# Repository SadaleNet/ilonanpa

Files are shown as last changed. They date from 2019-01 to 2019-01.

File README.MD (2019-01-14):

# Ilo Nanpa - Toki Pona Numeral Calculator

(sina sona e toki pona, la o tawa lipu [https://ilonanpa.sadale.net/](https://ilonanpa.sadale.net/). mi kepeken toki ike tan ni: nimi sona "Programming" li ike. toki ike Inli taso li lon lipu ni.)

Ilo Nanpa is a hardware calculator designed for Toki Pona Numeral. [Toki Pona](http://tokipona.org/) is a minimalist constructed language designed by jan Sonja with an obscure, non-base-10 numeral system.

This repository contains the source code of the firmware as well as the source files of hardware design. This readme file mainly describes the procedure of building the firmware as well as working with factory mode. For the usage of this device and other technical details, please refer to [the official English blogpost of Ilo Nanpa on sadale.net](https://sadale.net/58/).

# Repository Structure

* src/ - source code of the firmware
* pcb/ - KiCad hardware design files
* bin/ - Compiled source code (generated after running Makefile)

# Microcontroller

The microcontroller of this project is STM8S001J3.

# Dependencies

* Make (for Makefile)
* Compiler: sdcc
* Firmware uploading tool: stm8flash, to be used with stlinkv2.
* PCB Software: KiCad (for modification of hardware design. It isn't needed for firmware development)

# Building and Flashing the Firmware

* Run `make` to build the firmware.

* Connect stlink with Ilo Nanpa. On the backside of the device, there's a 3-pin male header on the top-left corner. The pin 1 is Vcc, pin 2 is ground and pin 3 is SWIM.

* Run `make flash-opt-bytes` to flash the option bytes (fusebit-like configuration). It maps ADC channel 2 to the ala-wan-tu button group. This operation only need to be performed once for each microcontroller. For some reason, the first run returns me an error. I have to run this command twice to get it work.

* Run `make flash` to upload the firmware to the microcontroller. For some reason, the first run of the command often fails. Perhaps it has something to do with clock configuration. I have to run this command twice to get it uploaded.

# Reprogramming the Device

To reprogram the device, hold the "pana" button before powering up the device. This prevents the device from leaving programming mode. As soon as "pana" is released, the device would leave programming mode and enter normal operation mode.

# Factory Mode

Due to the design of the device, ADC calibration procedure has to be performed for getting the button detection of the device work. This can be performed using factory mode. In addition, factory mode is able to perform key tests and LED brightness adjustment.

** If you're a holder of Ilo Nanpa and you have no idea on what this mode does, please do NOT enter factory mode. This mode would cause your device not to be able to properly detect key presses if it isn't used properly. **

Please ensure that you aren't touching any LEDs or resistors with your fingers during the process.

To enter factory mode:

1. Hold down the "ala" button and power the device on.

2. Wait for 5 seconds. The LEDs suno9,10,11,12 would turn on.

3. Press the buttons in the following sequence. ala, pana, luka, pana, ala, luka, luka, pana. If you press any of them wrong, the firmware would enter normal mode and would not enter factory mode.

4. Slide the en/weka slider switch to `en` position.

5. The LEDs suno1 and suno12 should light up. If suno8 is also lit, you're too slow and you have to slide the en/weka slider to `weka` position and back to `en` position again.

6. You're now in ADC calibration scene. Press the buttons in this sequence for 5 times: ala, wan, tu, luka, mute, ali, pana, kama, tenpo. This calibrates the ADC values when the slider is in `en` position. After this step, the ADC calibration values are saved to the EEPROM.

7. The LEDs suno1,8,12 should be lit. You've entered key test scene. The buttons are grouped as shown below:

	* suno1,2,3,4 <=> RELEASED,ala,wan,tu
	* suno8,9,10,11 <=> RELEASED,luka,mute,ali
	* suno12,13,14,15 <=> RELEASED,pana,kama,tenpo

	For example, when ala is pressed, suno2 would be lit. When wan is pressed, suno3 would be lit. When tu is pressed, suno4 would be lit. When none of ala, wan and tu is pressed, suno1 would be lit.

8. Repeat step 4 to 7, but with slider switch positioned at `weka` instead of `en`.

9. If you're in key test scene, you can enter brightness adjustment scene. To enter brightness adjustment scene, hold ala, luka and tenpo at the same time.

10. The higher the maxActionCount, the lower the brightness. In brightness adjustment scene, press wan to reduce maxActionCount by 10, tu to reduce maxActionCount by 1, mute to increase maxActionCount by 1, ali to increase maxActionCount by 10. The number shown on the LEDs is the current maxActionCount in Toki Pona Numeral.

11. To get back to key test scene from brightness adjustment scene, hold ala, luka and tenpo at the same time. To get back to ADC calibration scene, slide the slider switch in any scene.

# Working with Hardware Design
Just open up `pcb/ilonanpa.pro` with KiCad. The documentation of KiCad can be found on their website.

Please notice that unusual electronic designator is being used. Instead of R1, R2, R3 for resistors, we have awen1, awen2, awen3. It's designed in this way because this device is designed to have Toki Pona culture in mind. In case you're confused, please refer to the electronic symbol.

# License
This project is licensed under BSD 2-clause license.

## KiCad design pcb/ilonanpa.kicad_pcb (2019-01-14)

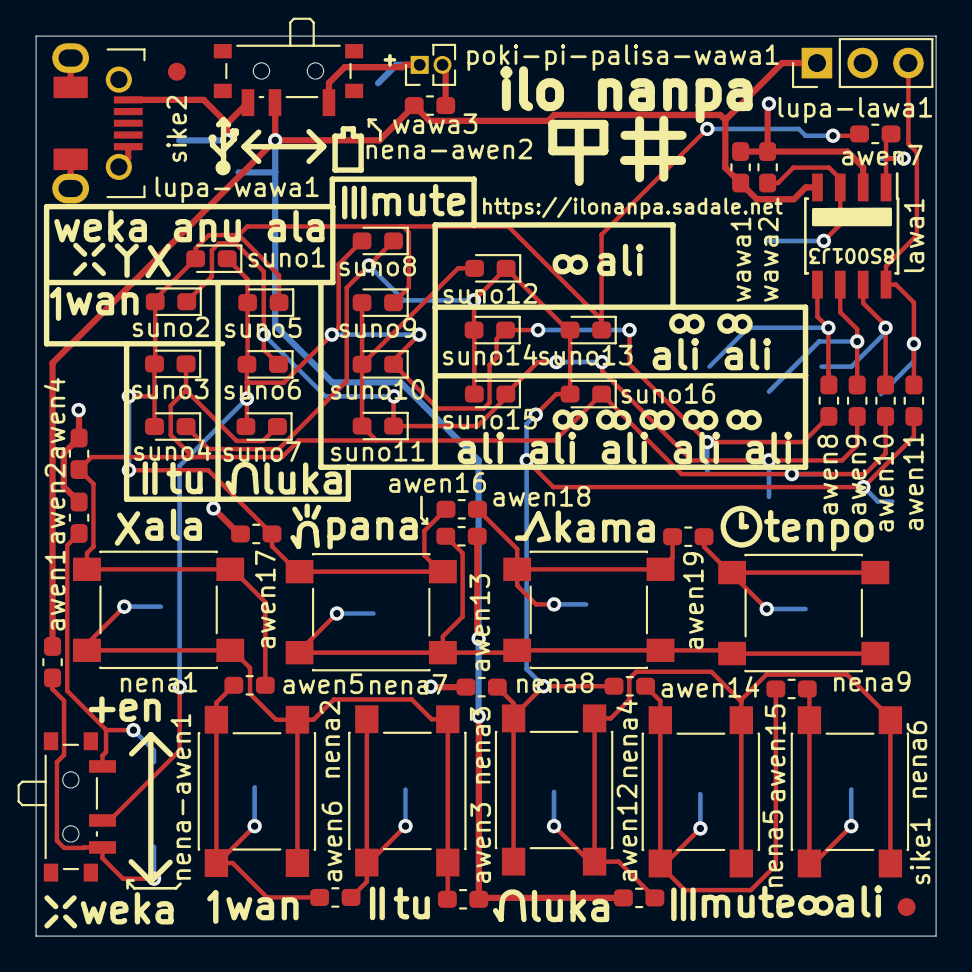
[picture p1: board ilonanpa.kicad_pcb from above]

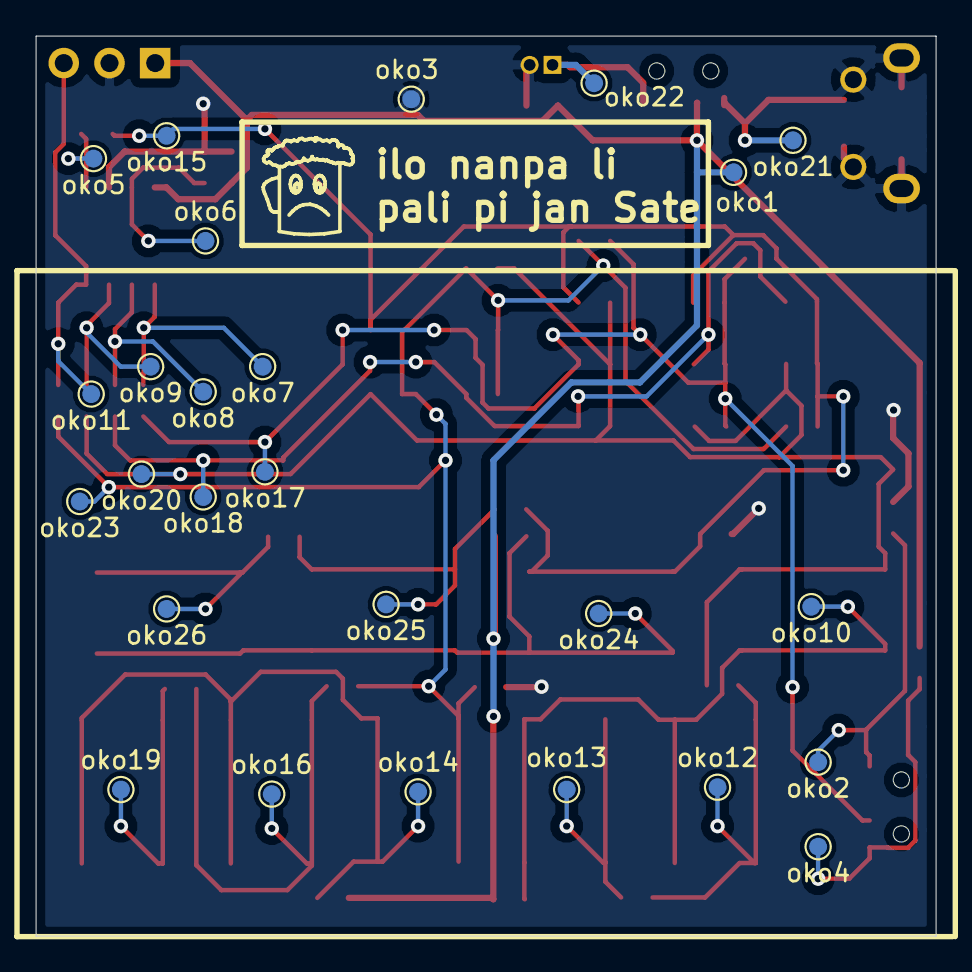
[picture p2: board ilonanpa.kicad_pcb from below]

Board: 2 copper layers, 50.0 x 50.0 mm, 81 parts (26 on the bottom side), 26 nets.

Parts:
awen1, awen2, awen4, awen13, awen17: 470k; R_0603_1608Metric_Pad1.05x0.95mm_HandSolder
awen3, awen12, awen16: 10k; R_0603_1608Metric_Pad1.05x0.95mm_HandSolder
awen5, awen6, awen14, awen15, awen18, awen19: 20k; R_0603_1608Metric_Pad1.05x0.95mm_HandSolder
awen7, awen8, awen9, awen10, awen11: 120; R_0603_1608Metric_Pad1.05x0.95mm_HandSolder
lawa1: STM8S001J3; SOIC-8_3.9x4.9mm_P1.27mm
lupa-lawa1: lupa lawa; PinHeader_1x03_P2.54mm_Vertical
lupa-wawa1: USB_B_Micro; USB_Micro-B_A01SB141B1-067
nena1: ala; SW_SPST_PTS645
nena2: wan; SW_SPST_PTS645
nena3: tu; SW_SPST_PTS645
nena4: luka; SW_SPST_PTS645
nena5: mute; SW_SPST_PTS645
nena6: ali; SW_SPST_PTS645
nena7: pana; SW_SPST_PTS645
nena8: kama; SW_SPST_PTS645
nena9: tenpo; SW_SPST_PTS645
nena-awen1: en anu weka; SW_SPDT_PCM12
nena-awen2: ante wawa; SW_SPDT_PCM12
oko1, oko2, oko3, oko4, oko5, oko6, oko7, oko8, oko9, oko10, oko11, oko12, oko13, oko14, oko15, oko16, oko17, oko18, oko19, oko20, oko21, oko22, oko23, oko24, oko25, oko26: oko; TestPoint_Pad_D1.0mm
poki-pi-palisa-wawa1: wawa palisa "AAA" tu wan; PinHeader_1x02_P1.27mm_Vertical
sike1, sike2: Fiducial_1mm_Dia_2mm_Outer
suno1: weka anu ala; LED_0603_1608Metric_Pad1.05x0.95mm_HandSolder
suno2: wan; LED_0603_1608Metric_Pad1.05x0.95mm_HandSolder
suno3, suno4: tu; LED_0603_1608Metric_Pad1.05x0.95mm_HandSolder
suno5, suno6, suno7: luka; LED_0603_1608Metric_Pad1.05x0.95mm_HandSolder
suno8, suno9, suno10, suno11: mute; LED_0603_1608Metric_Pad1.05x0.95mm_HandSolder
suno12: ali; LED_0603_1608Metric_Pad1.05x0.95mm_HandSolder
suno13, suno14: ali ali; LED_0603_1608Metric_Pad1.05x0.95mm_HandSolder
suno15, suno16: ali ali ali ali ali; LED_0603_1608Metric_Pad1.05x0.95mm_HandSolder
wawa1: 100n; C_0603_1608Metric_Pad1.05x0.95mm_HandSolder
wawa2: 2u2; C_0603_1608Metric_Pad1.05x0.95mm_HandSolder
wawa3: 10u; C_0603_1608Metric_Pad1.05x0.95mm_HandSolder

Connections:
/1: awen7.2, lawa1.1, oko5.1
/5: awen8.2, lawa1.5, oko7.1
/6: awen9.2, lawa1.6, oko8.1
/7: awen10.2, lawa1.7, oko9.1
/8: awen11.2, lawa1.8, lupa-lawa1.3, oko11.1
/A: awen7.1, awen17.2, awen18.1, nena7.2, oko15.1, suno1.2, suno2.2, suno3.2, suno4.2, suno5.1, suno9.1, suno13.1
/AIN2: awen4.2, awen5.1, awen10.1, nena1.2, oko20.1, suno3.1, suno7.1, suno9.2, suno10.2, suno11.2, suno12.2, suno16.1
/AIN4,5: awen11.1, awen13.2, awen14.1, nena4.2, oko23.1, suno4.1, suno8.1, suno12.1, suno13.2, suno14.2, suno15.2, suno16.2
/B: awen8.1, nena-awen1.2, oko17.1, suno1.1, suno5.2, suno6.2, suno7.2, suno8.2, suno10.1, suno14.1
/C: awen9.1, oko18.1, suno2.1, suno6.1, suno11.1, suno15.1
GND: awen2.2, awen4.1, awen13.1, awen17.1, lawa1.2, lupa-lawa1.2, lupa-wawa1.5, lupa-wawa1.6, oko3.1, poki-pi-palisa-wawa1.2, wawa1.1, wawa2.1, wawa3.2
unnamed: awen1.2, nena-awen1.3, oko4.1
unnamed: awen2.1, nena-awen1.1, oko2.1
unnamed: awen3.2, nena1.1, nena2.1, nena3.1, oko10.1
unnamed: awen5.2, awen6.1, nena2.2, oko12.1
unnamed: awen6.2, nena3.2, oko13.1
unnamed: awen12.2, nena4.1, nena5.1, nena6.1, oko14.1
unnamed: awen14.2, awen15.1, nena5.2, oko16.1
unnamed: awen15.2, nena6.2, oko19.1
unnamed: awen16.2, nena7.1, nena8.1, nena9.1, oko24.1
unnamed: awen18.2, awen19.1, nena8.2, oko25.1
unnamed: awen19.2, nena9.2, oko26.1
unnamed: lawa1.3, oko6.1, wawa2.2
unnamed: lupa-wawa1.1, nena-awen2.3, oko21.1
unnamed: nena-awen2.1, oko22.1, poki-pi-palisa-wawa1.1
VDD: awen1.1, awen3.1, awen12.1, awen16.1, lawa1.4, lupa-lawa1.1, nena-awen2.2, oko1.1, wawa1.2, wawa3.1

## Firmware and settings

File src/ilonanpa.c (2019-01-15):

/*
Copyright 2019 Wong Cho Ching <https://sadale.net>

Redistribution and use in source and binary forms, with or without modification, are permitted provided that the following conditions are met:

1. Redistributions of source code must retain the above copyright notice, this list of conditions and the following disclaimer.

2. Redistributions in binary form must reproduce the above copyright notice, this list of conditions and the following disclaimer in the documentation and/or other materials provided with the distribution.

THIS SOFTWARE IS PROVIDED BY THE COPYRIGHT HOLDERS AND CONTRIBUTORS "AS IS" AND ANY EXPRESS OR IMPLIED WARRANTIES, INCLUDING, BUT NOT LIMITED TO, THE IMPLIED WARRANTIES OF MERCHANTABILITY AND FITNESS FOR A PARTICULAR PURPOSE ARE DISCLAIMED. IN NO EVENT SHALL THE COPYRIGHT HOLDER OR CONTRIBUTORS BE LIABLE FOR ANY DIRECT, INDIRECT, INCIDENTAL, SPECIAL, EXEMPLARY, OR CONSEQUENTIAL DAMAGES (INCLUDING, BUT NOT LIMITED TO, PROCUREMENT OF SUBSTITUTE GOODS OR SERVICES; LOSS OF USE, DATA, OR PROFITS; OR BUSINESS INTERRUPTION) HOWEVER CAUSED AND ON ANY THEORY OF LIABILITY, WHETHER IN CONTRACT, STRICT LIABILITY, OR TORT (INCLUDING NEGLIGENCE OR OTHERWISE) ARISING IN ANY WAY OUT OF THE USE OF THIS SOFTWARE, EVEN IF ADVISED OF THE POSSIBILITY OF SUCH DAMAGE.
*/

#include <stdbool.h>
#include <stdint.h>
#include "stm8.h"

//Addresses of EEPROM values.
//For AWT/LMA/PKT, each of them are array of six values.
//For AWT, The first value is the minimum value of ALA reading at EN position
//The second value is the minimum value of WAN reading at EN position
//The third value is the minimum value of TU reading at EN position
//The next three values are the WEKA position correspondent of the previous three values.
#define EEPROM_AWT_THRESHOLD *(volatile uint16_t *)0x4000
#define EEPROM_LMA_THRESHOLD *(volatile uint16_t *)0x400C
#define EEPROM_PKT_THRESHOLD *(volatile uint16_t *)0x4018
#define EEPROM_SAVED_VALUE *(volatile int16_t *)0x4024
#define EEPROM_BRIGHTNESS *(volatile uint8_t *)0x4026
#define EEPROM_DEBUG *(volatile int16_t *)0x4028

//Timer-related handling
#define TIMER_FREQ 12500
#define MIN_MAX_ACTION_COUNTER 20
#define TIME_TO_ENTER_PASSWORD_MODE 62500 //5 seconds at 12500Hz
#define TIME_FOR_CALIBRATION_TIMEOUT 37500 //3 seconds at 12500Hz

//En/weka detection handling
#define EN_WEKA_DETECTION_FRAME 400 //en/weka should get detected every 0.032 second (at 12500Hz)
#define EN_WEKA_WAIT_FRAME 25 //We have to ensure 0.002s(25 frames) of no LEDs before checking the value of en/weka

//Minimum and maximum value that ilo nanpa can handle.
#define MAX_VALUE 1600
#define MIN_VALUE -1600

//Definition of LED ports and pins
#define LED_A_PORT    PD
#define LED_A_PIN     PIN6
#define LED_B_PORT    PA
#define LED_B_PIN     PIN3
#define LED_C_PORT    PB
#define LED_C_PIN     PIN4
#define LED_D_PORT    PC
#define LED_D_PIN     PIN4
#define LED_E_PORT    PD
#define LED_E_PIN     PIN5

//Port definition of buttons
#define EN_WEKA_PORT	PA
#define EN_WEKA_PIN		PIN3
#define AWT_PORT		PC
#define AWT_PIN			PIN4
#define LMA_PORT		PD
#define LMA_PIN			PIN5
#define PKT_PORT		PD
#define PKT_PIN			PIN6

//ADC channels for button groups
#define BUTTON_AWT_CHANNEL 2 //ala, wan, tu
#define BUTTON_LMA_CHANNEL 5 //luka, mute, ali [shared with debug pin!]
#define BUTTON_PKT_CHANNEL 6 //pana, kama, tenpo

//If the ADC reading is above this value, one of the button in the ADC group is pressed
#define MIN_ANALOG_VALUE 0x300

//For "frame" delay skipping. Used for maintaining the "fps".
uint8_t timer4TriggeredCount = 0;

//Debouncing value. A value is only accepted if the same value is read for 3 times consecutively
struct DebouncedValueU8_3 {
	uint8_t value[3];
	uint8_t offset;
};

//Push a new value to the deboucing ring buffer. Returns the debounced value on success, supplied default value on failure.
uint8_t debounced_value_u8_3_push_value(struct DebouncedValueU8_3* debouncedValueU8_3, uint8_t newValue, uint8_t defaultValue){
	debouncedValueU8_3->value[debouncedValueU8_3->offset++] = newValue;
	if(debouncedValueU8_3->offset>=sizeof(debouncedValueU8_3->value)/sizeof(*(debouncedValueU8_3->value)))
		debouncedValueU8_3->offset = 0;
	for(uint8_t i=1; i<( sizeof(debouncedValueU8_3->value)/sizeof(*(debouncedValueU8_3->value)) ); i++){
		if(debouncedValueU8_3->value[0]!=debouncedValueU8_3->value[i])
			return defaultValue; //Debounce failed. Returning the supplied default value
	}
	return debouncedValueU8_3->value[0]; //Debounce success!
}

uint16_t analog_read(uint8_t);
uint16_t analog_read_with_led_b_on(uint8_t channel);

//Detect which button is pressed based on ADC reading, current en/weka position and the threshold values supplied.
uint8_t button_read(uint16_t adcValue, bool wekaMode, volatile uint16_t *thresholds){
	uint8_t wekaOffset = wekaMode?3:0;
	if(adcValue >= thresholds[0+wekaOffset])
		return 1;
	else if(adcValue >= thresholds[1+wekaOffset])
		return 2;
	else if(adcValue >= thresholds[2+wekaOffset])
		return 3;
	else
		return 0;
}

//Function for litting charlieplex'd LEDs. 0~15: lit one LED. 
//16: lit all group A LEDs. 17: all group B. 18: C. 19: D. 20: all group A except "WEKA ANU ALA".
//16~19 is used for timer reaching minimum value (-1600)
//17~20 is used for timer reaching maximum value (1600)
//By litting 4 LEDs at once, it's brighter than litting up LED 0~15 one by one.
void litLed(int ledId) {
	#define CHARLIEPLEX_LED_OUTPUT(SRC, SINK) \
	/* Set pins to output mode */ \
	PORT(LED_##SRC##_PORT, DDR) |= LED_##SRC##_PIN; \
	PORT(LED_##SINK##_PORT, DDR) |= LED_##SINK##_PIN; \
	/* Set pins to push-pull mode (For open-drain only pins, this bit has no effect) */ \
	PORT(LED_##SRC##_PORT, CR1) |= LED_##SRC##_PIN; \
	PORT(LED_##SINK##_PORT, CR1) |= LED_##SINK##_PIN; \
	/* Set LED outputs */ \
	PORT(LED_##SRC##_PORT, ODR) |= LED_##SRC##_PIN; \
	PORT(LED_##SINK##_PORT, ODR) &= ~LED_##SINK##_PIN

	//LED_B_PIN
    PA_DDR &= ~(LED_B_PIN); //Setting the pins to INPUT mode
    PA_CR1 &= ~(LED_B_PIN); //Setting the pins to FLOATING mode. No pull up.
	//LED_C_PIN
    PB_DDR &= ~(LED_C_PIN); //Setting the pins to INPUT mode
    PB_CR1 &= ~(LED_C_PIN); //Setting the pins to FLOATING mode. No pull up.
    //LED_D_PIN
    PC_DDR &= ~(LED_D_PIN); //Setting the pins to INPUT mode
    PC_CR1 &= ~(LED_D_PIN); //Setting the pins to FLOATING mode. No pull up.
	//LED_A_PIN LED_E_PIN
    PD_DDR &= ~(LED_A_PIN|LED_E_PIN); //Setting the pins to INPUT mode
    PD_CR1 &= ~(LED_A_PIN|LED_E_PIN); //Setting the pins to FLOATING mode. No pull up.

	switch(ledId){
		case 0:		CHARLIEPLEX_LED_OUTPUT(A, B);	break;
		case 1:		CHARLIEPLEX_LED_OUTPUT(A, C);	break;
		case 2:		CHARLIEPLEX_LED_OUTPUT(A, D);	break;
		case 3:		CHARLIEPLEX_LED_OUTPUT(A, E);	break;
		case 4:		CHARLIEPLEX_LED_OUTPUT(B, A);	break;
		case 5:		CHARLIEPLEX_LED_OUTPUT(B, C);	break;
		case 6:		CHARLIEPLEX_LED_OUTPUT(B, D);	break;
		case 7:		CHARLIEPLEX_LED_OUTPUT(B, E);	break;
		case 8:		CHARLIEPLEX_LED_OUTPUT(D, A);	break;
		case 9:		CHARLIEPLEX_LED_OUTPUT(D, B);	break;
		case 10:	CHARLIEPLEX_LED_OUTPUT(D, C);	break;
		case 11:	CHARLIEPLEX_LED_OUTPUT(D, E);	break;
		case 12:	CHARLIEPLEX_LED_OUTPUT(E, B);	break; //Intentionally swapped with 13 because of hardware LED position
		case 13:	CHARLIEPLEX_LED_OUTPUT(E, A);	break; //Intentionally swapped with 12 because of hardware LED position
		case 14:	CHARLIEPLEX_LED_OUTPUT(E, C);	break;
		case 15:	CHARLIEPLEX_LED_OUTPUT(E, D);	break;
		case 16:
			CHARLIEPLEX_LED_OUTPUT(A, B);
			CHARLIEPLEX_LED_OUTPUT(A, C);
			CHARLIEPLEX_LED_OUTPUT(A, D);
			CHARLIEPLEX_LED_OUTPUT(A, E);
		break;
		case 17:
			CHARLIEPLEX_LED_OUTPUT(B, A);
			CHARLIEPLEX_LED_OUTPUT(B, C);
			CHARLIEPLEX_LED_OUTPUT(B, D);
			CHARLIEPLEX_LED_OUTPUT(B, E);
		break;
		case 18:
			CHARLIEPLEX_LED_OUTPUT(D, A);
			CHARLIEPLEX_LED_OUTPUT(D, B);
			CHARLIEPLEX_LED_OUTPUT(D, C);
			CHARLIEPLEX_LED_OUTPUT(D, E);
		break;
		case 19:
			CHARLIEPLEX_LED_OUTPUT(E, B);
			CHARLIEPLEX_LED_OUTPUT(E, A);
			CHARLIEPLEX_LED_OUTPUT(E, C);
			CHARLIEPLEX_LED_OUTPUT(E, D);
		break;
		case 20:
			CHARLIEPLEX_LED_OUTPUT(A, C);
			CHARLIEPLEX_LED_OUTPUT(A, D);
			CHARLIEPLEX_LED_OUTPUT(A, E);
		break;
		default:
		break;
	}
}

//TIM4 Update/overflow ISR. 12500Hz.
void TIM4_update(void) __interrupt(TIM4_OVR_UIF_IRQ) {
	timer4TriggeredCount++;

    // Clear Timer 4 Status Register 1 Update Interrupt Flag (UIF) (bit 0)
    TIM4_SR &= ~TIM_SR_UIF;
}

//Read ADC value
uint16_t analog_read(uint8_t channel) {
	ADC_TDRL |= (1 << channel); //Disable Schmitt triggers of channels to be used as recommended by the reference manual.
	ADC_CR1 |= ADC_CR1_ADON; //Enable ADC. The first "ADC_CR1 |= ADC_CR1_ADON" wakes it up from power down mode.
	ADC_CSR = channel; // Select channel 2 (AIN2=PC4)
    ADC_CR1 &= ~ADC_CR1_CONT; // Single conversion mode
    ADC_CR1 |= ADC_CR1_ADON; // The second "ADC_CR1 |= ADC_CR1_ADON" starts conversion.
    do { nop(); } while ((ADC_CSR >> 7) == 0);
    ADC_CSR &= ~ADC_CSR_EOC; // Clear "End of conversion"-flag
    ADC_CR1 &= ~ADC_CR1_ADON; //Power down the ADC
	ADC_TDRL &= ~(1 << channel); //Enable schmitt triggers so that digital IO would work
    return (ADC_DRH << 2) | (ADC_DRL >> 6);  // Left aligned
}

//Read ADC value with LED B pin set to HIGH.
//This function exists to reduce the undesirable effect of ADC reading cause by other group of buttons as well as en/weka slider
//Without this function, ALA+LUKA+TENPO buttons combination doesn't work properly
uint16_t analog_read_with_led_b_on(uint8_t channel) {
	uint16_t ret;
	//Set LED B to PUSH-PULL OUTPUT HIGH for measurement
	PORT(LED_B_PORT, DDR) |= LED_B_PIN;
	PORT(LED_B_PORT, CR1) |= LED_B_PIN;
	PORT(LED_B_PORT, ODR) |= LED_B_PIN;
	ret = analog_read(channel);
	//Set LED B to INPUT FLOATING after completion of measurement
	PORT(LED_B_PORT, DDR) &= ~LED_B_PIN;
	PORT(LED_B_PORT, CR1) &= ~LED_B_PIN;
	return ret;
}

//Unlocks the EEPROM to allows writing data onto it.
void eeprom_unlock(void) {
	//Unlock EEPROM if required
	if(!(FLASH_IAPSR&FLASH_IAPSR_DUL)){
		FLASH_DUKR = FLASH_DUKR_KEY_1;
		FLASH_DUKR = FLASH_DUKR_KEY_2;
	}

	//Wait until the EEPROM is unlocked
	while(!(FLASH_IAPSR&FLASH_IAPSR_DUL));
}

//Lock the EEPROM to prevent it from being written.
void eeprom_lock(void) {
	FLASH_IAPSR &= ~FLASH_IAPSR_DUL;
}

//Convert numeric value into LED state.
uint16_t convertValueToLedState(int16_t value){
	//Value to LED mapping
	#define LED_WEKA_ANU_ALA (1 << 0)
	#define LED_WAN (1 << 1)
	#define LED_TU_1 (1 << 2)
	#define LED_TU_2 (1 << 3)
	#define LED_LUKA_1 (1 << 4)
	#define LED_LUKA_2 (1 << 5)
	#define LED_LUKA_3 (1 << 6)
	#define LED_MUTE_1 (1 << 7)
	#define LED_MUTE_2 (1 << 8)
	#define LED_MUTE_3 (1 << 9)
	#define LED_MUTE_4 (1 << 10)
	#define LED_ALI (1 << 11)
	#define LED_ALI_ALI_1 (1 << 12)
	#define LED_ALI_ALI_2 (1 << 13)
	#define LED_ALI_ALI_ALI_ALI_ALI_1 (1 << 14)
	#define LED_ALI_ALI_ALI_ALI_ALI_2 (1 << 15)

	//If the current value is higher than the LED value,
	//lit up the LED and substract the current value by the LED value.
	#define LED_CONVERT_VALUE(RET, VALUE, DEDUCTABLE, LED_VALUE) \
		if(VALUE >= DEDUCTABLE){ \
			RET |= LED_VALUE; \
			VALUE -= DEDUCTABLE; \
		}

	//Lit up the "WEKA ANU ALA" LED for 0 or negative values
	uint16_t ret = 0;
	if(value<=0){
		ret |= LED_WEKA_ANU_ALA;
		value = -value;
	}

	//Perform the value-to-LED conversion for each LED.
	LED_CONVERT_VALUE(ret, value, 500, LED_ALI_ALI_ALI_ALI_ALI_1);
	LED_CONVERT_VALUE(ret, value, 500, LED_ALI_ALI_ALI_ALI_ALI_2);
	LED_CONVERT_VALUE(ret, value, 200, LED_ALI_ALI_1);
	LED_CONVERT_VALUE(ret, value, 200, LED_ALI_ALI_2);
	LED_CONVERT_VALUE(ret, value, 100, LED_ALI);
	LED_CONVERT_VALUE(ret, value, 20, LED_MUTE_1);
	LED_CONVERT_VALUE(ret, value, 20, LED_MUTE_2);
	LED_CONVERT_VALUE(ret, value, 20, LED_MUTE_3);
	LED_CONVERT_VALUE(ret, value, 20, LED_MUTE_4);
	LED_CONVERT_VALUE(ret, value, 5, LED_LUKA_1);
	LED_CONVERT_VALUE(ret, value, 5, LED_LUKA_2);
	LED_CONVERT_VALUE(ret, value, 5, LED_LUKA_3);
	LED_CONVERT_VALUE(ret, value, 2, LED_TU_1);
	LED_CONVERT_VALUE(ret, value, 2, LED_TU_2);
	LED_CONVERT_VALUE(ret, value, 1, LED_WAN);

	return ret;
}

//Disables programming mode and allows the programming pin to be used for ADC conversion
void disable_swim_and_disable_schmitt_trigger(void){
	// Disables SWIM
	CFG_GCR |= CFG_GCR_SWD; //Disables SWIM
	PD_CR1 &= ~PIN1; //Set the SWIM pin to floating mode
}

//This is the first mode entered on power up.
//It allows the user to stay in programming mode, or enter factory mode (via password mode)
//Returns true for entering password mode, returns false for normal mode.
//Get stuck here without returning if it's staying in programming mode.
bool programmingMode(void){
	//To enter programming mode, hold both PKT before power on
	//To enter password mode, hold both AWT before power on
	uint16_t passwordModeTimer = 0;

	//If these two buttons are held for 5 seconds, we enter password mode, which can lead to factory mode
	while((analog_read_with_led_b_on(BUTTON_AWT_CHANNEL)>=MIN_ANALOG_VALUE)){
		if(passwordModeTimer++ >= TIME_TO_ENTER_PASSWORD_MODE)
			return true;
		wfi(); //Frame-limiting with TIM4
	}

	//If PKT button is held, we can enter programming mode
	while((analog_read_with_led_b_on(BUTTON_PKT_CHANNEL)>=MIN_ANALOG_VALUE));

	return false;
}

//If the user enters the correct password, it would lead to factory mode.
//Returns true if the password is correct, false else.
bool passwordMode(void){
	wfi(); //Add a delay of 12500Hz before performing next measurement
	bool previousAwtButtonValue = (analog_read_with_led_b_on(BUTTON_AWT_CHANNEL)>=MIN_ANALOG_VALUE);
	wfi(); //Add a delay of 12500Hz before performing next measurement
	bool previousLmaButtonValue = (analog_read_with_led_b_on(BUTTON_LMA_CHANNEL)>=MIN_ANALOG_VALUE);
	wfi(); //Add a delay of 12500Hz before performing next measurement
	bool previousPktButtonValue = (analog_read_with_led_b_on(BUTTON_PKT_CHANNEL)>=MIN_ANALOG_VALUE);
	wfi(); //Add a delay of 12500Hz before performing next measurement
	bool awtButtonValue = false;
	bool lmaButtonValue = false;
	bool pktButtonValue = false;
	struct DebouncedValueU8_3 debouncedValueAwt;
	struct DebouncedValueU8_3 debouncedValueLma;
	struct DebouncedValueU8_3 debouncedValuePkt;
	uint8_t actionCounter = 0;

	bool success = false;
	uint8_t password[] = {1,3,2,3,1,2,2,3};
	uint8_t currentPasswordPos = 0;
	while(true){
		if(actionCounter==0){
			awtButtonValue = debounced_value_u8_3_push_value(&debouncedValueAwt, 
										(analog_read_with_led_b_on(BUTTON_AWT_CHANNEL)>=MIN_ANALOG_VALUE),
										previousAwtButtonValue);
		}else if(actionCounter==1){
			lmaButtonValue = debounced_value_u8_3_push_value(&debouncedValueLma, 
										(analog_read_with_led_b_on(BUTTON_LMA_CHANNEL)>=MIN_ANALOG_VALUE),
										previousLmaButtonValue);
		}else if(actionCounter==2){
			pktButtonValue = debounced_value_u8_3_push_value(&debouncedValuePkt, 
										(analog_read_with_led_b_on(BUTTON_PKT_CHANNEL)>=MIN_ANALOG_VALUE),
										previousPktButtonValue);
		}else if(actionCounter==3){
			int currentKey = 0;
			if(!previousAwtButtonValue && awtButtonValue)
				currentKey = 1;
			else if(!previousLmaButtonValue && lmaButtonValue)
				currentKey = 2;
			else if(!previousPktButtonValue && pktButtonValue)
				currentKey = 3;
			if(currentKey!=0){
				if(currentKey == password[currentPasswordPos]){
					currentPasswordPos++;
					if(currentPasswordPos>=sizeof(password)/sizeof(*password)){
						success = true;
						break;
					}
				}else{
					break; //Wrong password. Going back to normal mode!
				}
			}
			previousAwtButtonValue = awtButtonValue;
			previousLmaButtonValue = lmaButtonValue;
			previousPktButtonValue = pktButtonValue;
		}else if(actionCounter==4){
			litLed(18);
		}else if(actionCounter==5){
			litLed(-1);
		}
		actionCounter++;
		if(actionCounter>=MIN_MAX_ACTION_COUNTER)
			actionCounter = 0;
		wfi(); //Frame-limiting with TIM4
	}
	if(!success)
		return false;

	//Wait until all keys are released
	while((analog_read_with_led_b_on(BUTTON_AWT_CHANNEL)>=MIN_ANALOG_VALUE) ||
		(analog_read_with_led_b_on(BUTTON_LMA_CHANNEL)>=MIN_ANALOG_VALUE) ||
		(analog_read_with_led_b_on(BUTTON_PKT_CHANNEL)>=MIN_ANALOG_VALUE));

	return true;
}
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
int main(void)
{
	//safetyDelay(); //Prevents SWIM pin lock-up

	//Setting the HSI clock to 16Mhz. 2Mhz simply isn't sufficient for our main loop!
    CLK_CKDIVR = 0;

    //Setup timer 4
    TIM4_PSCR = 7; // 16e6/(2**7)== 125000 Hz
    TIM4_ARR = 9; // TIM4_ARR=49. 125000/(9+1) = 12500Hz
    // TIM4_IER (Interrupt Enable Register), Update interrupt (UIE) (bit 0)
    TIM4_IER |= TIM_IER_UIE;
    // TIM4_CR1 – Timer 4 Control Register 1, Counter ENable bit (CEN) (bit 0)
    TIM4_CR1 |= TIM_CR1_CEN;

	adc_init();
	if(programmingMode()){
		disable_swim_and_disable_schmitt_trigger();
		if(passwordMode())
			factoryMode();
	}else{
		disable_swim_and_disable_schmitt_trigger();
	}

	normalMode();

	return 0; //Should never reach here.
}

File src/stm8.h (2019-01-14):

// Adapted from https://github.com/jukkas/stm8-sdcc-examples/blob/master/stm8.h
/*
 * Register definitions for STM8S103 (and STM8S003)
 * Still incomplete.
 */
#ifndef _STH8_H
#define _STH8_H


/* Handy macros for GPIO */
#define CONCAT(a, b)    a##_##b
#define PORT(a, b)      CONCAT(a , b)

#define PIN0    (1 << 0)
#define PIN1    (1 << 1)
#define PIN2    (1 << 2)
#define PIN3    (1 << 3)
#define PIN4    (1 << 4)
#define PIN5    (1 << 5)
#define PIN6    (1 << 6)
#define PIN7    (1 << 7)

/* Register addresses */

/* Clock */
#define CLK_CKDIVR	*(volatile unsigned char *)0x50C6

/* GPIO */
#define PA_ODR *(volatile unsigned char *)0x5000
#define PA_IDR *(volatile unsigned char *)0x5001
#define PA_DDR *(volatile unsigned char *)0x5002
#define PA_CR1 *(volatile unsigned char *)0x5003
#define PA_CR2 *(volatile unsigned char *)0x5004

#define PB_ODR *(volatile unsigned char *)0x5005
#define PB_IDR *(volatile unsigned char *)0x5006
#define PB_DDR *(volatile unsigned char *)0x5007
#define PB_CR1 *(volatile unsigned char *)0x5008
#define PB_CR2 *(volatile unsigned char *)0x5009

#define PC_ODR *(volatile unsigned char *)0x500A
#define PC_IDR *(volatile unsigned char *)0x500B
#define PC_DDR *(volatile unsigned char *)0x500C
#define PC_CR1 *(volatile unsigned char *)0x500D
#define PC_CR2 *(volatile unsigned char *)0x500E

#define PD_ODR *(volatile unsigned char *)0x500F
#define PD_IDR *(volatile unsigned char *)0x5010
#define PD_DDR *(volatile unsigned char *)0x5011
#define PD_CR1 *(volatile unsigned char *)0x5012
#define PD_CR2 *(volatile unsigned char *)0x5013

/* FLASH */
/* For stm8s001j3 */
#define FLASH_CR1 *(volatile unsigned char *)0x505A
#define FLASH_CR2 *(volatile unsigned char *)0x505B
#define FLASH_NCR2 *(volatile unsigned char *)0x505C
#define FLASH_FPR *(volatile unsigned char *)0x505D
#define FLASH_NFPR *(volatile unsigned char *)0x505E
#define FLASH_IAPSR *(volatile unsigned char *)0x505F
#define FLASH_PUKR *(volatile unsigned char *)0x5062
#define FLASH_DUKR *(volatile unsigned char *)0x5064

#define FLASH_PUKR_KEY_1 0x56
#define FLASH_PUKR_KEY_2 0xAE

#define FLASH_DUKR_KEY_1 0xAE
#define FLASH_DUKR_KEY_2 0x56

#define FLASH_IAPSR_WR_PG_DIS (1 << 0)
#define FLASH_IAPSR_PUL (1 << 1)
#define FLASH_IAPSR_EOP (1 << 2)
#define FLASH_IAPSR_DUL (1 << 3)
#define FLASH_IAPSR_HVOFF (1 << 6)


/* UART */
#define UART1_SR *(volatile unsigned char *)0x5230
#define UART1_DR *(volatile unsigned char *)0x5231
#define UART1_BRR1 *(volatile unsigned char *)0x5232
#define UART1_BRR2 *(volatile unsigned char *)0x5233
#define UART1_CR1 *(volatile unsigned char *)0x5234
#define UART1_CR2 *(volatile unsigned char *)0x5235
#define UART1_CR3 *(volatile unsigned char *)0x5236
#define UART1_CR4 *(volatile unsigned char *)0x5237
#define UART1_CR5 *(volatile unsigned char *)0x5238
#define UART1_GTR *(volatile unsigned char *)0x5239
#define UART1_PSCR *(volatile unsigned char *)0x523A

#define UART_SR_TXE (1 << 7)
#define UART_SR_TC (1 << 6)
#define UART_SR_RXNE (1 << 5)
#define UART_SR_IDLE (1 << 4)
#define UART_SR_OR (1 << 3)
#define UART_SR_NF (1 << 2)
#define UART_SR_FE (1 << 1)
#define UART_SR_PE (1 << 0)

#define UART_CR1_R8 (1 << 7)
#define UART_CR1_T8 (1 << 6)
#define UART_CR1_UARTD (1 << 5)
#define UART_CR1_M (1 << 4)
#define UART_CR1_WAKE (1 << 3)
#define UART_CR1_PCEN (1 << 2)
#define UART_CR1_PS (1 << 1)
#define UART_CR1_PIEN (1 << 0)

#define UART_CR2_TIEN (1 << 7)
#define UART_CR2_TCIEN (1 << 6)
#define UART_CR2_RIEN (1 << 5)
#define UART_CR2_ILIEN (1 << 4)
#define UART_CR2_TEN (1 << 3)
#define UART_CR2_REN (1 << 2)
#define UART_CR2_RWU (1 << 1)
#define UART_CR2_SBK (1 << 0)

#define UART_CR3_LINEN (1 << 6)
#define UART_CR3_STOP2 (1 << 5)
#define UART_CR3_STOP1 (1 << 4)
#define UART_CR3_CLKEN (1 << 3)
#define UART_CR3_CPOL (1 << 2)
#define UART_CR3_CPHA (1 << 1)
#define UART_CR3_LBCL (1 << 0)

/* Timers */
#define TIM1_CR1 *(volatile unsigned char *)0x5250
#define TIM1_CR2 *(volatile unsigned char *)0x5251
#define TIM1_SMCR *(volatile unsigned char *)0x5252
#define TIM1_ETR *(volatile unsigned char *)0x5253
#define TIM1_IER *(volatile unsigned char *)0x5254
#define TIM1_SR1 *(volatile unsigned char *)0x5255
#define TIM1_SR2 *(volatile unsigned char *)0x5256
#define TIM1_EGR *(volatile unsigned char *)0x5257
#define TIM1_CCMR1 *(volatile unsigned char *)0x5258
#define TIM1_CCMR2 *(volatile unsigned char *)0x5259
#define TIM1_CCMR3 *(volatile unsigned char *)0x525A
#define TIM1_CCMR4 *(volatile unsigned char *)0x525B
#define TIM1_CCER1 *(volatile unsigned char *)0x525C
#define TIM1_CCER2 *(volatile unsigned char *)0x525D
#define TIM1_CNTRH *(volatile unsigned char *)0x525E
#define TIM1_CNTRL *(volatile unsigned char *)0x525F
#define TIM1_PSCRH *(volatile unsigned char *)0x5260
#define TIM1_PSCRL *(volatile unsigned char *)0x5261
#define TIM1_ARRH *(volatile unsigned char *)0x5262
#define TIM1_ARRL *(volatile unsigned char *)0x5263
#define TIM1_RCR *(volatile unsigned char *)0x5264
#define TIM1_CCR1H *(volatile unsigned char *)0x5265
#define TIM1_CCR1L *(volatile unsigned char *)0x5266
#define TIM1_CCR2H *(volatile unsigned char *)0x5267
#define TIM1_CCR2L *(volatile unsigned char *)0x5268
#define TIM1_CCR3H *(volatile unsigned char *)0x5269
#define TIM1_CCR3L *(volatile unsigned char *)0x526A
#define TIM1_CCR4H *(volatile unsigned char *)0x526B
#define TIM1_CCR4L *(volatile unsigned char *)0x526C
#define TIM1_BKR *(volatile unsigned char *)0x526D
#define TIM1_DTR *(volatile unsigned char *)0x526E
#define TIM1_OISR *(volatile unsigned char *)0x526F

/* Note these are for STM8S103 and STM8S003
   STM8S105,104/207/208 are different */
#define TIM2_CR1 *(volatile unsigned char *)0x5300
#define TIM2_CR2 *(volatile unsigned char *)0x5301
#define TIM2_SMCR *(volatile unsigned char *)0x5302
#define TIM2_IER *(volatile unsigned char *)0x5303
#define TIM2_SR1 *(volatile unsigned char *)0x5304
#define TIM2_SR2 *(volatile unsigned char *)0x5305
#define TIM2_EGR *(volatile unsigned char *)0x5306
#define TIM2_CCMR1 *(volatile unsigned char *)0x5307
#define TIM2_CCMR2 *(volatile unsigned char *)0x5308
#define TIM2_CCMR3 *(volatile unsigned char *)0x5309
#define TIM2_CCER1 *(volatile unsigned char *)0x530A
#define TIM2_CCER2 *(volatile unsigned char *)0x530B
#define TIM2_CNTRH *(volatile unsigned char *)0x530C
#define TIM2_CNTRL *(volatile unsigned char *)0x530D
#define TIM2_PSCR *(volatile unsigned char *)0x530E
#define TIM2_ARRH *(volatile unsigned char *)0x530F
#define TIM2_ARRL *(volatile unsigned char *)0x5310
#define TIM2_CCR1H *(volatile unsigned char *)0x5311
#define TIM2_CCR1L *(volatile unsigned char *)0x5312
#define TIM2_CCR2H *(volatile unsigned char *)0x5313
#define TIM2_CCR2L *(volatile unsigned char *)0x5314
#define TIM2_CCR3H *(volatile unsigned char *)0x5315
#define TIM2_CCR3L *(volatile unsigned char *)0x5316
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

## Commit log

2019-01-15 Fixed inconsistency between pin definition of LMA_PIN and ADC channel of BUTTON_LMA_CHANNEL
    [ilonanpa.c]
2019-01-15 Turns on ADC only when needed.
2019-01-15 Sharing the same internal pin for both input handling and output handling.
2019-01-15 Bugfix: The initial state of en/weka isn't detected on power on. Before this fix, if the user pressed a button in weka state right after power on, it would be regarded as en instead of weka.
    [ilonanpa.c]
